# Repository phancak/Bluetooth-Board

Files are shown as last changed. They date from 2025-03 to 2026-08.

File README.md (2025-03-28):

# STM32WB55CGU6 Bluetooth Expansion Board  

## Overview  
This project showcases a **high-performance Bluetooth expansion board** based on the **STM32WB55CGU6 module**, a dual-core **Cortex-M4/M0+** MCU with integrated **Bluetooth 5.2** support. Designed for seamless connectivity and modular integration, the board enables **wireless communication** for a wide range of embedded applications.  

This expansion board provides **I2C, USART, and SPI interfaces**, making it a versatile platform for **IoT, industrial control, and smart embedded systems**.  

## Features  
✅ **STM32WB55CGU6 MCU** – Dual-core architecture with BLE 5.2 support  
✅ **Multiple Communication Interfaces** – I2C, USART, SPI for flexible connectivity  
✅ **Ultra-Low Power Operation** – Optimized for battery-powered applications  
✅ **Compact and Modular Design** – Easy integration with host MCUs  
✅ **Secure BLE Communication** – Integrated AES-256 encryption for data protection  

## Applications  
- **IoT & Smart Devices** – Wireless sensors, home automation, asset tracking  
- **Industrial Automation** – Wireless monitoring, factory communication systems  
- **Embedded Development** – Prototyping for BLE-enabled applications  

## Getting Started  
### Hardware Requirements  
- STM32WB55CGU6 Bluetooth Expansion Board  
- Host MCU (STM32, ESP32, Raspberry Pi, etc.)  
- Power Supply (3.3V)  
- USB-to-Serial Debugging Tools  

### Software Requirements  
- **STM32CubeIDE** – Firmware development  
- **STM32CubeWB** – BLE stack and middleware  
- **ST-Link or J-Link** – Debugging and flashing tools  

## Setup & Usage  
1. **Power the Board** – Connect 3.3V power via USB or external source.  
2. **Establish Communication** – Interface using I2C, USART, or SPI.  
3. **Flash Firmware** – Use STM32CubeIDE for code deployment.  
4. **Test Bluetooth Functionality** – Verify BLE communication via a mobile app or BLE-enabled host.  

## Repository Structure  
/Hardware - PCB schematics and design files
/Schematic - Circuit diagrams (PDF, KiCad, Altium, etc.)
/PCB - Board layout files (Gerber, BOM, assembly files)

## Future Enhancements  
- 🔹 **Extended Power Optimization** – Further reducing energy consumption  
- 🔹 **Additional BLE Profiles** – Custom Bluetooth services for enhanced functionality  
- 🔹 **Integration with Cloud Services** – Enable remote monitoring and control  

## License  
This project is open-source under the **MIT License**.  

---

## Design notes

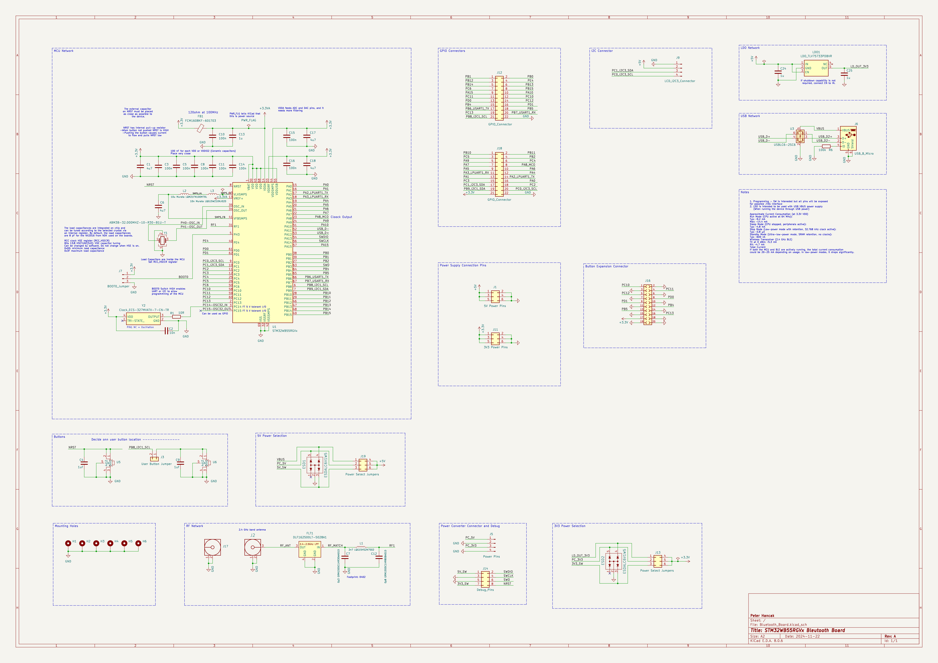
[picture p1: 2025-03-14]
Bluetooth-Board-Schematics.png

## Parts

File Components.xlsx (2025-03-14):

Antenna
 | Adam Tech | ANT-20090EB56 | RF ANT, LORA& WIFI 2.4, OMNI-DIR | https://www.digikey.ca/en/products/detail/adam-tech/ANT-20090EB56/16123707
 | Würth Elektronik | 60312202114508 | SMA PCB END LAUNCH JACK ROUND PO | https://www.digikey.ca/en/products/detail/würth-elektronik/60312202114508/10106994
Bluetooth
GPS
Wifi
LoRa
Headers
Pin headders
Capacitors
 | Size | Footprint
 | 4u7 | 0805
 | 100n | 0805
 | 10p
 | 0p3
 | 0p8
 | 1u
 | Ferrite Bead
 | FCM1608KF-601T03 | 0603
 | Coils (L)
 | LQG15HS2N7S02 | 0402 (1005 Metric) | FIXED IND 2.7NH 800MA 0.15OHM SM | https://www.digikey.ca/en/products/detail/murata-electronics/LQG15HS2N7S02D/662864
L2 | Murata LQM21FN100M70L | 0805 (2012 Metric) | FIXED IND 10UH 100MA 780MOHM SMD | https://www.digikey.ca/en/products/detail/murata-electronics/LQM21FN100M70L/1016188
L3 | Murata LQG15WZ10NJ02D | 0402 (1005 Metric) | FIXED IND 10NH 500MA 0.19OHM SMD | https://www.digikey.ca/en/products/detail/murata-electronics/LQG15WZ10NJ02D/6798669

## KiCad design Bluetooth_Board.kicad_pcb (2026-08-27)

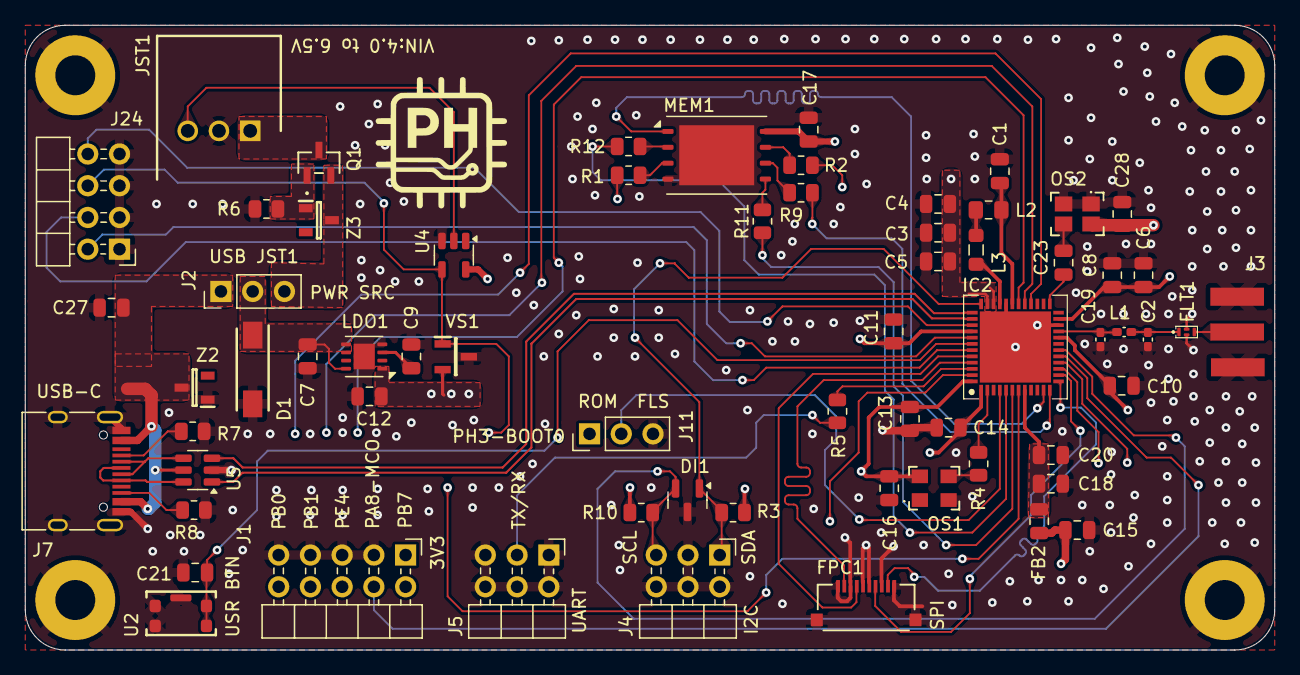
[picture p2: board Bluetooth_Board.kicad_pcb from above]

Board: 4 copper layers, 100.0 x 50.0 mm, 69 parts (0 on the bottom side), 56 nets.

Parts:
C1, C4, C6, C18, C27: 4u7; C_0805_2012Metric
C2: 0p3 GRM1555C1HR30WA01D; C_0402_1005Metric_Pad0.74x0.62mm_HandSolder
C3, C5, C8, C10, C11, C13, C14, C15, C17, C20, C28: 100n; C_0805_2012Metric
C7: 1u; C_0805_2012Metric
C9, C16: 10n; C_0805_2012Metric
C12: 2u2; C_0805_2012Metric
C19: 0p8 GRM1555C1HR80BA01D; C_0402_1005Metric_Pad0.74x0.62mm_HandSolder
C21: 1uF; C_0805_2012Metric
C23: 1n; C_0805_2012Metric
D1: SMAJ6.0A; DO-214AC-2
DI1: Diode_PESD5V0U2BT-Q; SOT-23
FB2: BLM21AG121BH1D; C_0805_2012Metric
FLT1: DLF162500LT-5028A1
FPC1: FPC_10051922-1010ELF; FPC_10051922_1010
H1, H2, H3, H4: MountingHole_Pad; MountingHole_3.2mm_M3_Pad
IC2: STM32WB55CGU6; STM32WB55CGU6_QFN50P700X700X60-49N-D
J1: I/O_HDR; PinHeader_2x05_P2.54mm_Horizontal
J2: I2S_OR_LJ_OUT; PinHeader_1x03_P2.54mm_Vertical
J3: SMA PCB END LAUNCH JACK ROUND PO; SMA Clip Mount Adapter (top)
J4: I2C1_Headers; PinHeader_2x03_P2.54mm_Horizontal_Court
J5: UART1_HDR; PinHeader_2x03_P2.54mm_Horizontal_Court
J7: USB_C_Receptacle_USB2.0_16P; USB_C_Receptacle_HRO_TYPE-C-31-M-12
J11: BOOT0_Jumper; PinHeader_1x03_P2.54mm_Vertical
J24: SWDB; PinHeader_2x04_P2.54mm_Horizontal
JST1: JST_S3B-XH-2.54; JST_S3B-XH-SHDRRA3W64P0X250_1X3_990X1150X610P
L1: 2n7 LQG15HS2N7S02; L_0402_1005Metric_Pad0.77x0.64mm_HandSolder
L2: 10u Murata LQM21FN100M70L; L_0805_2012Metric_Pad1.15x1.40mm_HandSolder
L3: 10n Murata LQG15WZ10NJ02D; L_0805_2012Metric_Pad1.05x1.20mm_HandSolder
LDO1: LDO_LDLN050PU33R; DFN-8-1EP_3x3mm_P0.65mm_EP1.7x2.05mm
MEM1: MX35LF2G24AD-Z4I; WDFN-8-1EP_8x6mm_P1.27mm_EP6x4.8mm
OS1: Oscillator_ECS-327MVATX-3-CN-TR; Oscillator_ECS327MVATX3CNTR
OS2: Oscillator_ATX-11-F-32.000MHZ-F05-T; Oscillator_ECSTXO32CSMV320ANTR
Q1: MOSFET_SI2333DDS-T1-BE3; MOSFET_ SI2333DDS_SOT_DS-T1-BE3_VIS
R1, R2, R5, R9, R11, R12: 33R; R_0805_2012Metric
R3, R10: 10k; R_0805_2012Metric
R4: 10R; R_0805_2012Metric
R6: 100k; R_0805_2012Metric
R7, R8: 5k1; R_0805_2012Metric
U2: Button_KMR231GLFS
U4: SN74LVC1G07DBVR; SOT-23-5
U5: USBLC6-2SC6; SOT-23-6
VS1: VS_STM1818TWX7F; SOT-23-3_SOT103P237X112-3N
Z2, Z3: Diode_BZX84C6V2-7-F; Diode_BZX84C6V2_SOT96P240X110-3N

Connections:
+3.3V: C3.1, C4.1, C5.1, C6.1, C8.1, C10.1, C11.1, C12.1, C13.1, C14.1, C15.1, C16.2, C17.1, C28.2, FB2.2, IC2.1 (VBAT), IC2.20 (VDD_1), IC2.23 (VDDRF), IC2.34 (VDDSMPS), IC2.35 (VDD_2), IC2.40 (VDDUSB), IC2.48 (VDD_3), J1.1, J11.1, LDO1.1 (OUT), MEM1.8 (VCC), OS1.4 (VDD), OS2.4 (VDD), R3.1, R10.1, U4.5 (VCC), VS1.2 (VCC)
+3.3VA: C18.1, C20.1, FB2.1, IC2.8 (VDDA)
/Interfaces/I2C_SCL_HDR: DI1.2 (K2), IC2.18 (PA9), J4.5, R10.2
/Interfaces/I2C_SDA_HDR: DI1.1 (K1), IC2.36 (PA10), J4.1, R3.2
/Interfaces/I/O_HDR0: IC2.47 (PB7), J1.2
/Interfaces/I/O_HDR1: IC2.17 (PA8), J1.4
/Interfaces/I/O_HDR2: IC2.30 (PE4), J1.6
/Interfaces/I/O_HDR3: IC2.29 (PB1), J1.8
/Interfaces/I/O_HDR4: IC2.28 (PB0), J1.10
/Interfaces/NRST: IC2.7 (NRST), J24.6, U4.4, VS1.1 (~RST)
/Interfaces/SPI_CLK: FPC1.7, IC2.14 (PA5)
/Interfaces/SPI_CS: FPC1.9, IC2.13 (PA4)
/Interfaces/SPI_MISO: FPC1.4, IC2.44 (PB4)
/Interfaces/SPI_MOSI: FPC1.2, IC2.45 (PB5)
/Interfaces/SWCLK: IC2.41 (PA14), J24.2
/Interfaces/SWDIO: IC2.39 (PA13), J24.8
/Interfaces/SWO: IC2.43 (PB3), J24.4
/Interfaces/UART1_TX/RX: IC2.46 (PB6), R5.1
/Interfaces/USR_BTN: C21.2, IC2.42 (PA15), U2.1, U2.2
/Power_Management/MOSFET_PWR: Q1.1 (G), R6.1, Z3.1 (A)
/Power_Management/PWR+: JST1.1 (PWR+), Q1.3 (D)
/Power_Management/PWR+_PP: J2.3, Q1.2 (S), Z3.3 (K)
/Power_Management/RST_PWR: JST1.3 (RST), U4.2
/Power_Management/VIN_LDLN050PU33R: C7.1, D1.1 (K), J2.2, LDO1.5 (EN), LDO1.8 (IN)
/RF, USB/RF1: C19.1, IC2.21 (RF1), L1.1
/RF, USB/RF_ANT: FLT1.3 (OUT), J3.3 (Signal)
/RF, USB/RF_MATCH: C2.1, FLT1.1 (IN), L1.2
/RF, USB/USB_D2+: J7.A6 (D+), J7.B6 (D+), U5.6 (I/O1)
/RF, USB/USB_D2-: J7.A7 (D-), J7.B7 (D-), U5.4 (I/O2)
/RF, USB/USB_DI_D2+: IC2.38 (PA12), U5.1 (I/O1)
/RF, USB/USB_DI_D2-: IC2.37 (PA11), U5.3 (I/O2)
/STM32WB55CGU6/BOOT0: IC2.4 (PH3-BOOT0), J11.2
/STM32WB55CGU6/OSC_IN: C23.1, IC2.25 (OSC_IN)
/STM32WB55CGU6/OSC_OUTPUT: C23.2, OS2.3 (OUTPUT)
/STM32WB55CGU6/PA2_QUADSPI_BK1_NCS: IC2.11 (PA2), MEM1.1 (CS#)
/STM32WB55CGU6/PA3_QUADSPI_CLK: IC2.12 (PA3), R9.1
/STM32WB55CGU6/PA6_QUADSPI_BK1_IO3: IC2.15 (PA6), R2.1
/STM32WB55CGU6/PA7_QUADSPI_BK1_IO2: IC2.16 (PA7), R12.1
/STM32WB55CGU6/PB8_QUADSPI_BK1_IO1: IC2.5 (PB8), R1.2
/STM32WB55CGU6/PB9_QUADSPI_BK1_IO0: IC2.6 (PB9), R11.1
/STM32WB55CGU6/SMPS_FB: C1.1, IC2.31 (VFBSMPS), L2.1
/STM32WB55CGU6/SMPS_LX: IC2.33 (VLXSMPS), L3.2
/STM32WB55CGU6/SMPS_LXL: L2.2, L3.1
GND: C1.2, C2.2, C3.2, C4.2, C5.2, C6.2, C7.2, C8.2, C9.2, C10.2, C11.2, C12.2, C13.2, C14.2, C15.2, C16.1, C17.2, C18.2, C19.2, C20.2, C21.1, C27.2, C28.1, D1.2 (A), DI1.3 (CC), FLT1.2 (GND), FLT1.4 (GND), FPC1.1, FPC1.3, FPC1.5, FPC1.6, FPC1.8, FPC1.10, FPC1.11 (MP1), FPC1.12 (MP2), H1.1, H2.1, H3.1, H4.1, IC2.22 (VSSRF), IC2.32 (VSSSMPS), IC2.49 (GND), J1.3, J1.5, J1.7, J1.9, J3.1 (GND), J3.2 (GND), J4.2, J4.3, J4.4, J4.6, J5.1, J5.2, J5.4, J5.5, J5.6, J7.A1 (GND), J7.A12 (GND), J7.B1 (GND), J7.B12 (GND), J7.S1 (SHIELD), J11.3, J24.1, J24.3, J24.5, J24.7, JST1.2 (PWR-), LDO1.4 (GND_1), LDO1.9 (GND_2), MEM1.4 (GND), MEM1.9 (GND), OS1.2 (GND), OS2.1 (GND_1), OS2.2 (GND_2), R6.2, R7.2, R8.2, U2.3, U2.4, U2.5 (GND), U4.3 (GND), U5.2 (GND), VS1.3 (VSS), Z2.1 (A)
unnamed: IC2.2 (PC14-OSC32_IN), R4.1
unnamed: J5.3, R5.2
unnamed: J7.A5 (CC1), R7.1
unnamed: J7.B5 (CC2), R8.1
unnamed: C9.1, LDO1.3 (FB)
unnamed: MEM1.7 (HOLD#/SIO3), R2.2
unnamed: MEM1.6 (SCLK), R9.2
unnamed: MEM1.5 (SI/SIO0), R11.2
unnamed: MEM1.2 (SO/SIO1), R1.1
unnamed: MEM1.3 (WP#/SIO2), R12.2
unnamed: OS1.3 (OUTPUT), R4.2
VBUS+: C27.1, J2.1, J7.A4 (VBUS), J7.A9 (VBUS), J7.B4 (VBUS), J7.B9 (VBUS), U5.5 (VBUS), Z2.3 (K)
